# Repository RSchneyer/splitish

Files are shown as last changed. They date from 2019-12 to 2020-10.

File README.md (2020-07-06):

# splitish
My first attempt at designing a mechanical keyboard. Split-ish 4x12 ortholinear layout designed for Kailh Choc switches. Rev 1 works, but is far from perfect, so order at your own risk.
v1 assembled
version 2 now exists, but I haven't had it fabricated though. Should still work.
v2 front render
v2 back render

Firmware can be found [here](hhttps://github.com/qmk/qmk_firmware/tree/master/keyboards/splitish)
___
Made with lots of help from [Ai03's PCB design guide](https://wiki.ai03.me/books/pcb-design)

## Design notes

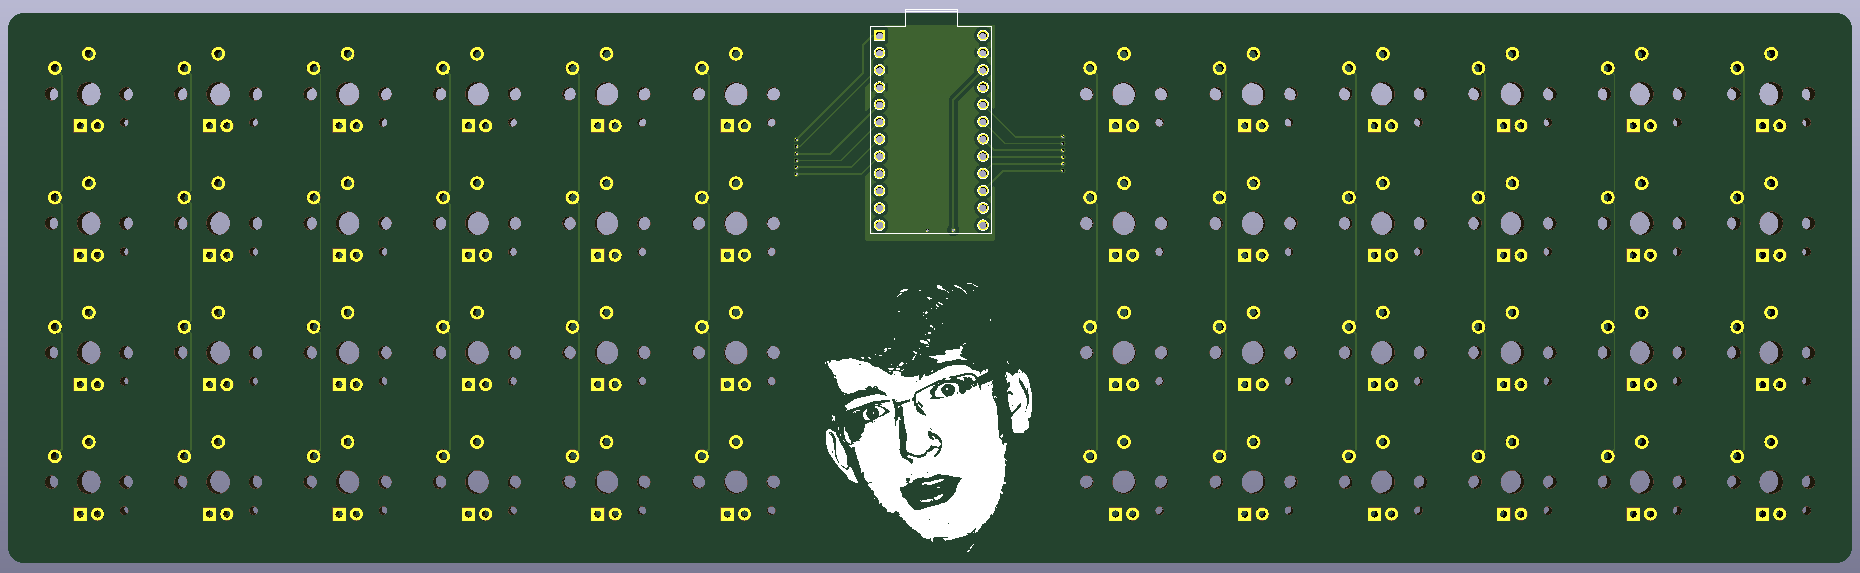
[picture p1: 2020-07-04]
media/splitish_back_v2.PNG

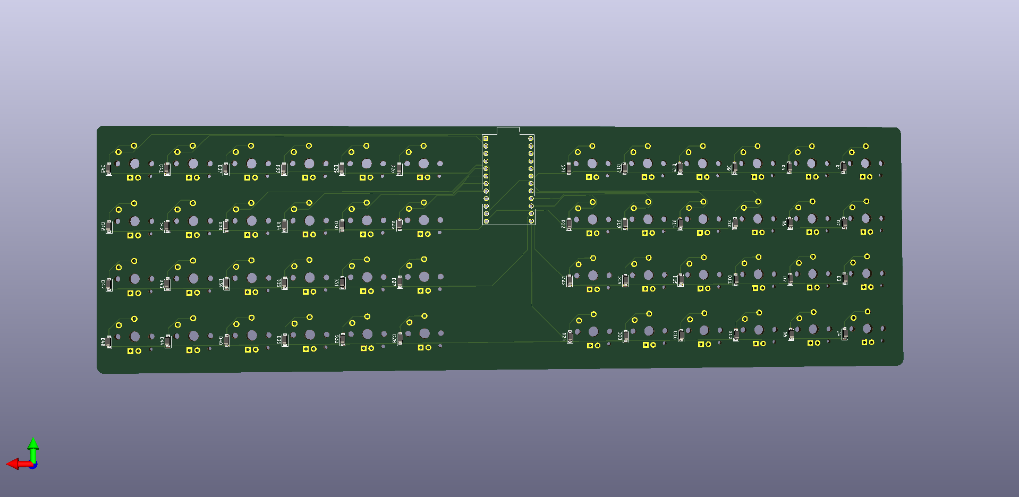
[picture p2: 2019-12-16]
media/starter-ortho-render-back.png

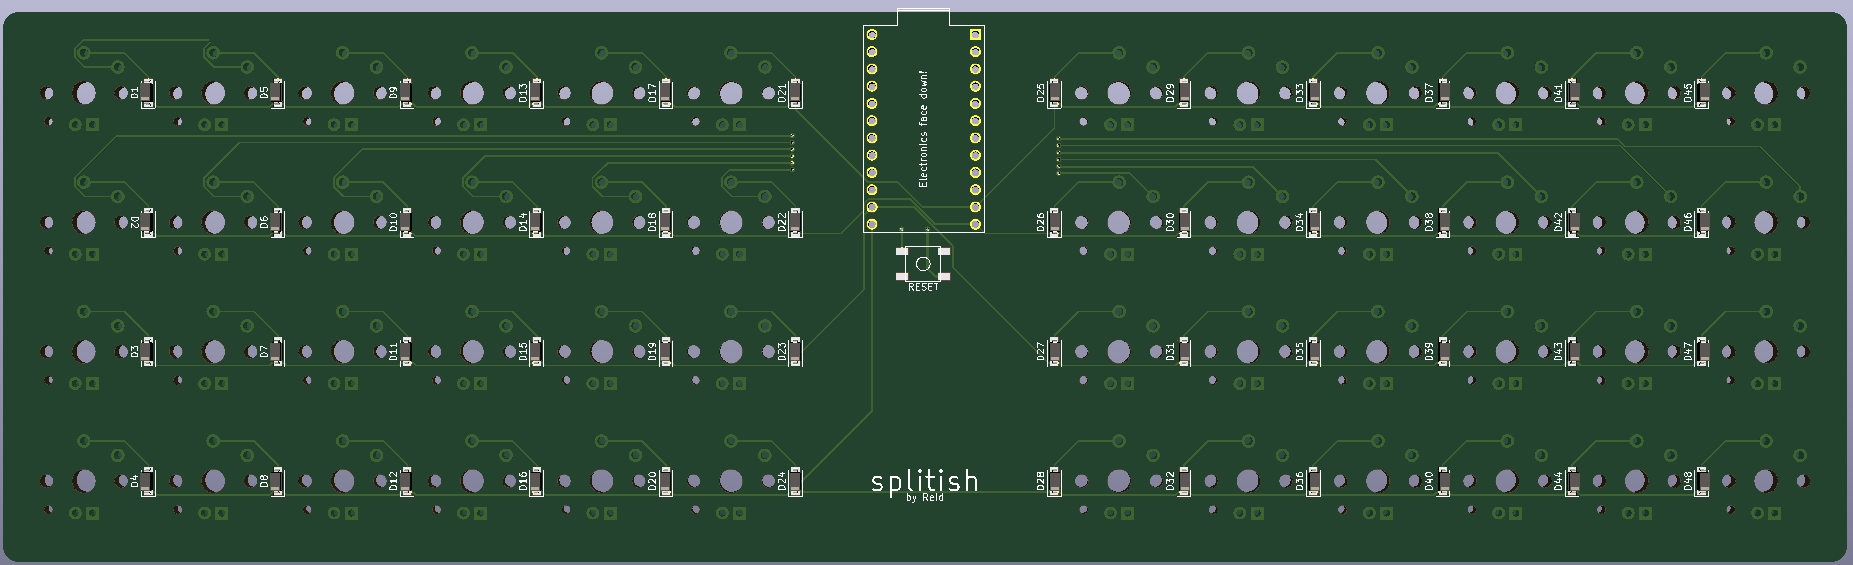
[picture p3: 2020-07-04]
media/splitish_front_v2.PNG

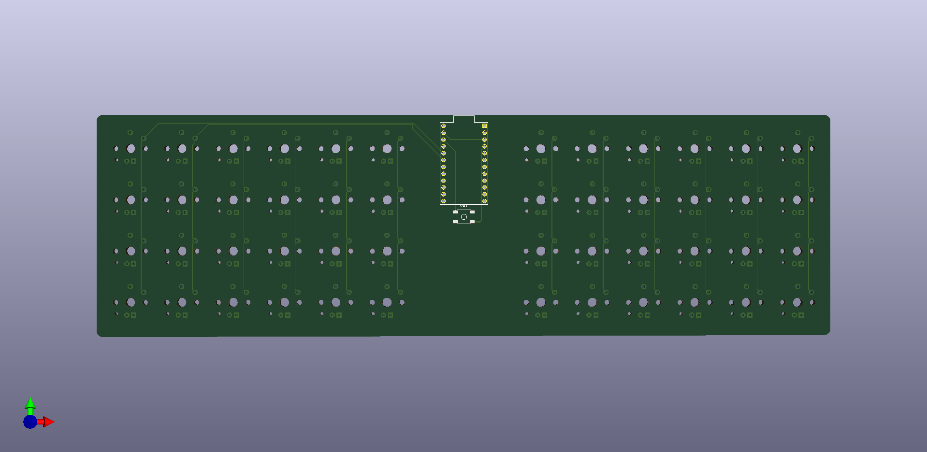
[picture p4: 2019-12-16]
media/starter-ortho-render-front.png

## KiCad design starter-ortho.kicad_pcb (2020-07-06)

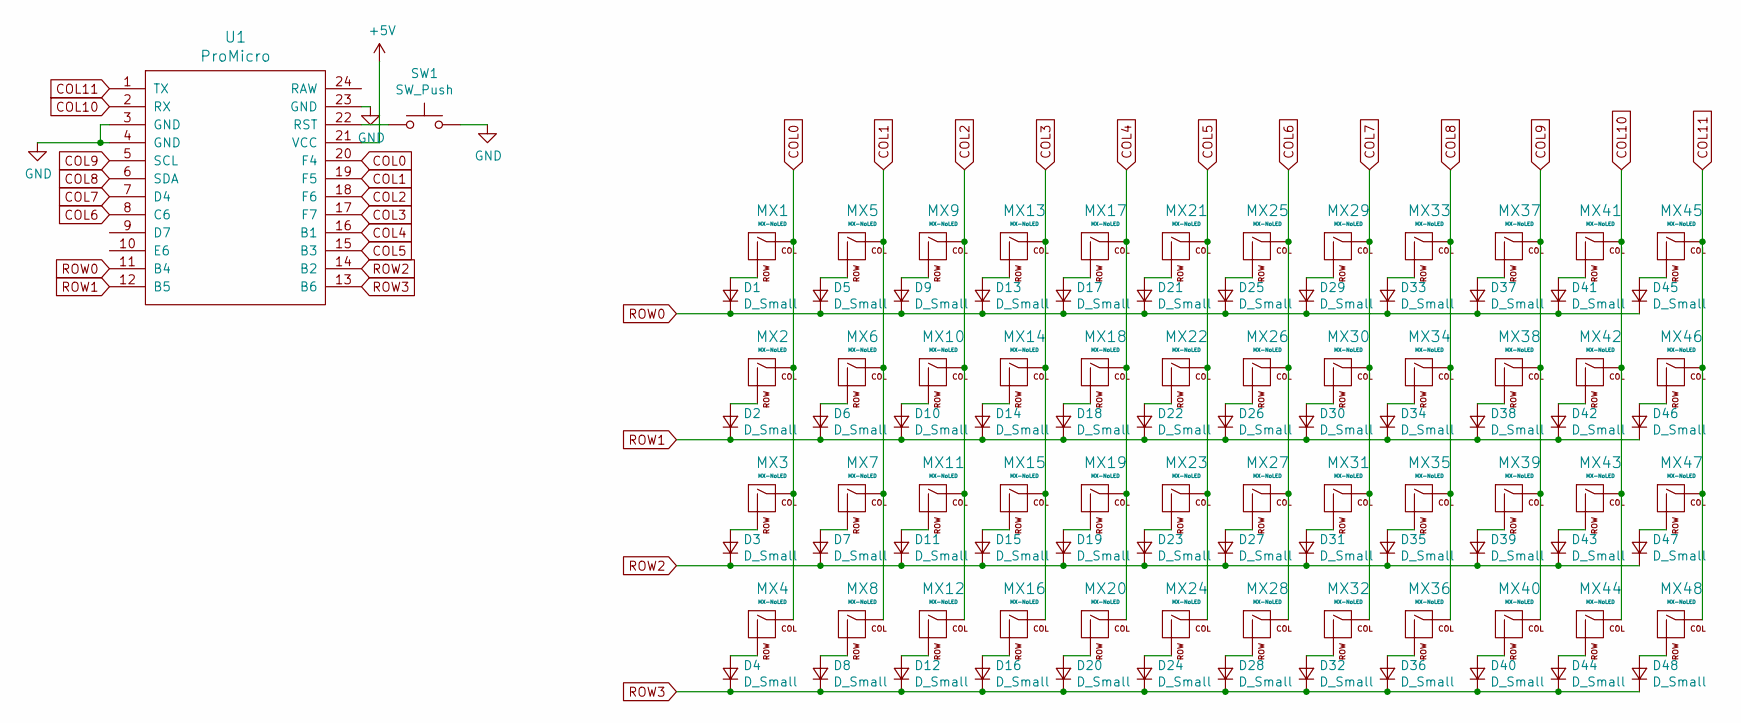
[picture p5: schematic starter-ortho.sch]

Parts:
D1, D2, D3, D4, D5, D6, D7, D8, D9, D10, D11, D12, D13, D14, D15, D16, D17, D18, D19, D20, D21, D22, D23, D24, D25, D26, D27, D28, D29, D30, D31, D32, D33, D34, D35, D36, D37, D38, D39, D40, D41, D42, D43, D44, D45, D46, D47, D48: D_Small; D_SOD-123
MX1, MX2, MX3, MX4, MX5, MX6, MX7, MX8, MX9, MX10, MX11, MX12, MX13, MX14, MX15, MX16, MX17, MX18, MX19, MX20, MX21, MX22, MX23, MX24, MX25, MX26, MX27, MX28, MX29, MX30, MX31, MX32, MX33, MX34, MX35, MX36, MX37, MX38, MX39, MX40, MX41, MX42, MX43, MX44, MX45, MX46, MX47, MX48: MX-NoLED; KailhChoc-1U
SW1: SW_Push; SKQG-1155865
U1: ProMicro

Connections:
+5V: U1.21 (VCC)
COL0: MX1.1 (COL), MX2.1 (COL), MX3.1 (COL), MX4.1 (COL), U1.20 (F4)
COL1: MX5.1 (COL), MX6.1 (COL), MX7.1 (COL), MX8.1 (COL), U1.19 (F5)
COL2: MX9.1 (COL), MX10.1 (COL), MX11.1 (COL), MX12.1 (COL), U1.18 (F6)
COL3: MX13.1 (COL), MX14.1 (COL), MX15.1 (COL), MX16.1 (COL), U1.17 (F7)
COL4: MX17.1 (COL), MX18.1 (COL), MX19.1 (COL), MX20.1 (COL), U1.16 (B1)
COL5: MX21.1 (COL), MX22.1 (COL), MX23.1 (COL), MX24.1 (COL), U1.15 (B3)
COL6: MX25.1 (COL), MX26.1 (COL), MX27.1 (COL), MX28.1 (COL), U1.8 (C6)
COL7: MX29.1 (COL), MX30.1 (COL), MX31.1 (COL), MX32.1 (COL), U1.7 (D4)
COL8: MX33.1 (COL), MX34.1 (COL), MX35.1 (COL), MX36.1 (COL), U1.6 (SDA)
COL9: MX37.1 (COL), MX38.1 (COL), MX39.1 (COL), MX40.1 (COL), U1.5 (SCL)
COL10: MX41.1 (COL), MX42.1 (COL), MX43.1 (COL), MX44.1 (COL), U1.2 (RX)
COL11: MX45.1 (COL), MX46.1 (COL), MX47.1 (COL), MX48.1 (COL), U1.1 (TX)
GND: SW1.2, U1.3 (GND), U1.4 (GND), U1.23 (GND); also elsewhere on the board
unnamed: D1.2 (A), MX1.2 (ROW)
unnamed: D2.2 (A), MX2.2 (ROW)
unnamed: D3.2 (A), MX3.2 (ROW)
unnamed: D4.2 (A), MX4.2 (ROW)
unnamed: D5.2 (A), MX5.2 (ROW)
unnamed: D6.2 (A), MX6.2 (ROW)
unnamed: D7.2 (A), MX7.2 (ROW)
unnamed: D8.2 (A), MX8.2 (ROW)
unnamed: D9.2 (A), MX9.2 (ROW)
unnamed: D10.2 (A), MX10.2 (ROW)
unnamed: D11.2 (A), MX11.2 (ROW)
unnamed: D12.2 (A), MX12.2 (ROW)
unnamed: D13.2 (A), MX13.2 (ROW)
unnamed: D14.2 (A), MX14.2 (ROW)
unnamed: D15.2 (A), MX15.2 (ROW)
unnamed: D16.2 (A), MX16.2 (ROW)
unnamed: D17.2 (A), MX17.2 (ROW)
unnamed: D18.2 (A), MX18.2 (ROW)
unnamed: D19.2 (A), MX19.2 (ROW)
unnamed: D20.2 (A), MX20.2 (ROW)
unnamed: D21.2 (A), MX21.2 (ROW)
unnamed: D22.2 (A), MX22.2 (ROW)
unnamed: D23.2 (A), MX23.2 (ROW)
unnamed: D24.2 (A), MX24.2 (ROW)
unnamed: D25.2 (A), MX25.2 (ROW)
unnamed: D26.2 (A), MX26.2 (ROW)
unnamed: D27.2 (A), MX27.2 (ROW)
unnamed: D28.2 (A), MX28.2 (ROW)
unnamed: D29.2 (A), MX29.2 (ROW)
unnamed: D30.2 (A), MX30.2 (ROW)
unnamed: D31.2 (A), MX31.2 (ROW)
unnamed: D32.2 (A), MX32.2 (ROW)
unnamed: D33.2 (A), MX33.2 (ROW)
unnamed: D34.2 (A), MX34.2 (ROW)
unnamed: D35.2 (A), MX35.2 (ROW)
unnamed: D36.2 (A), MX36.2 (ROW)
unnamed: D37.2 (A), MX37.2 (ROW)
unnamed: D38.2 (A), MX38.2 (ROW)
unnamed: D39.2 (A), MX39.2 (ROW)
unnamed: D40.2 (A), MX40.2 (ROW)
unnamed: D41.2 (A), MX41.2 (ROW)
unnamed: D42.2 (A), MX42.2 (ROW)
unnamed: D43.2 (A), MX43.2 (ROW)
unnamed: D44.2 (A), MX44.2 (ROW)
unnamed: D45.2 (A), MX45.2 (ROW)
unnamed: D46.2 (A), MX46.2 (ROW)
unnamed: D47.2 (A), MX47.2 (ROW)
unnamed: D48.2 (A), MX48.2 (ROW)
unnamed 62: SW1.1, U1.22 (RST); also elsewhere on the board
ROW0: D1.1 (K), D5.1 (K), D9.1 (K), D13.1 (K), D17.1 (K), D21.1 (K), D25.1 (K), D29.1 (K), D33.1 (K), D37.1 (K), D41.1 (K), D45.1 (K), U1.11 (B4)
ROW1: D2.1 (K), D6.1 (K), D10.1 (K), D14.1 (K), D18.1 (K), D22.1 (K), D26.1 (K), D30.1 (K), D34.1 (K), D38.1 (K), D42.1 (K), D46.1 (K), U1.12 (B5)
ROW2: D3.1 (K), D7.1 (K), D11.1 (K), D15.1 (K), D19.1 (K), D23.1 (K), D27.1 (K), D31.1 (K), D35.1 (K), D39.1 (K), D43.1 (K), D47.1 (K), U1.14 (B2)
ROW3: D4.1 (K), D8.1 (K), D12.1 (K), D16.1 (K), D20.1 (K), D24.1 (K), D28.1 (K), D32.1 (K), D36.1 (K), D40.1 (K), D44.1 (K), D48.1 (K), U1.13 (B6)

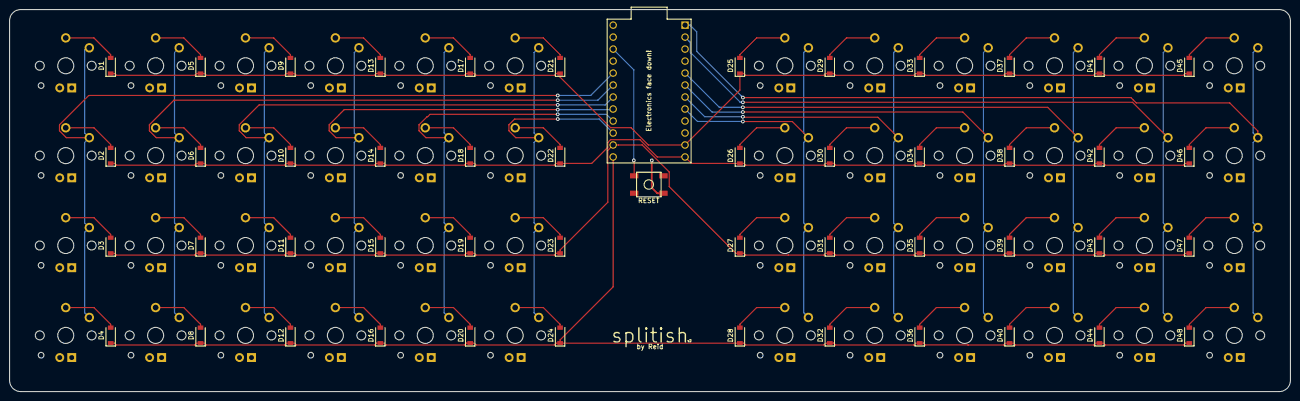
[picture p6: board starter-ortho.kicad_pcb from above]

Board: 2 copper layers, 271.5 x 81.0 mm, 98 parts (1 on the bottom side), 66 nets.

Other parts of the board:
RESET: SW_Push; SKQG-1155865

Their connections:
GND: RESET.2; also elsewhere on the board
unnamed 62: RESET.1; also elsewhere on the board

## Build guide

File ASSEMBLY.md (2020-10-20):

# Assembling the splitish

## Parts List
| Item | Quantity | Price | Where to Buy | Notes |
|---|---|---|---|---|
| splitish PCB | 1 | ~$25/5 PCBs  | JLCPCB (or your preferred PCB fab) | |
| Kailh Choc Switches | 48 | $6/10 switches | [Novelkeys](https://novelkeys.xyz/collections/switches/products/kailh-low-profile-switches)  | |
| Kailh Choc Keycaps  | 48 | ??? | ??? | NK used to carry them, idk where to get them now |
| Pro Micro | 1 | $7.99 | [SpaceCat](https://spacecat.design/collections/do-it-yourself/products/pro-micro-board) | Elite-C should also work, if you wanna spend $$$ |
| SMD Reset Switch | 1 | $0.69 | [SpaceCat](https://spacecat.design/collections/do-it-yourself/products/smd-switch-alps) | |
| 1N4148W-TP Diodes | 48 | $0.17/each | [Digi-Key](https://www.digikey.com/en/products/detail/micro-commercial-co/1N4148W-TP/717311) | |
| Rubber Feet | Many | Depends | [Amazon](https://www.amazon.com/322Pcs-Cabinet-Bumpers-Adhesive-Dampening/dp/B07BHP4NGY) | I'm sure there are plenty of other alternatives  |

## Step 1
Carefully solder all 48 SMD diodes to the bottom of the PCB. On both versions of the splitish PCB, the Cathode end of the diode (the end with the little line) should be facing the user when the keyboard is being used.

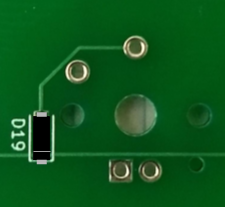
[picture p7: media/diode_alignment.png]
diode alignment


# Step 2
Now that all 48 diodes are properly soldered, you can solder in all 48 switches. The switches should have PCB mount legs that will help align the switch and keep it in place while you solder the metal pins, but a piece of tape can also be used to hold a switch in place.

# Step 3
After soldering all the switches, the next step is to solder the reset button and the Pro Micro. Solder the header pin strips to the PCB first, then the Pro Micro on top, aligned so that all the onboard components face the splitish PCB.

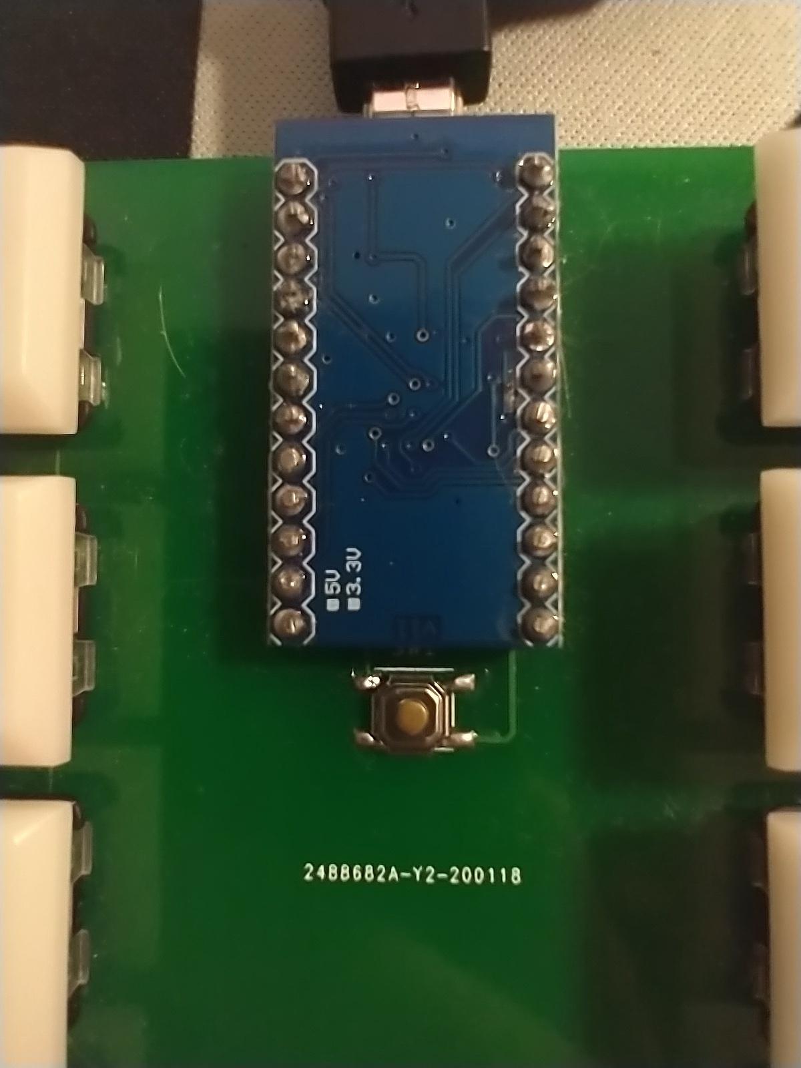
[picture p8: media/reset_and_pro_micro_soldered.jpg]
pro micro and diode


# Step 4
Attach the rubber bumpons/feet to the underside of the PCB, so that all the solder joints are not touching the work surface. Attach the keycaps, and using QMK, flash the default firmware to the splitish. Assuming you have a QMK environment properly setup on your PC, the command should be

`qmk compile -kb splitish -km default`

Assuming the keyboard now works, you're done with assembly! Wasn't that easy?

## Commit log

2019-12-16 Inital Commit
    [starter-ortho.kicad_pcb, starter-ortho.sch]
2019-12-16 schematic complete
2019-12-16 created PCB layout
    [starter-ortho.sch]
2019-12-16 Added edges and M2 holes
    [starter-ortho.kicad_pcb]
2019-12-16 Routed traces (poorly)
    [starter-ortho.kicad_pcb, starter-ortho.sch]
2019-12-16 undid edge cuts
    [starter-ortho.kicad_pcb]
2019-12-16 we're doing choc switches now baby
    [starter-ortho.kicad_pcb, starter-ortho.sch]
2019-12-16 all traces routed
    done well? we'll see...
    [starter-ortho.kicad_pcb, starter-ortho.sch]
2019-12-16 PCB done?
    [starter-ortho.kicad_pcb]
2019-12-16 removed name from silkscreen
    [starter-ortho.kicad_pcb]
2019-12-16 generated gerber files
    [starter-ortho-B_Cu.gbl, starter-ortho-B_Mask.gbs, starter-ortho-B_SilkS.gbo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]
2019-12-16 re-added silkscreen
    [starter-ortho.kicad_pcb]
2020-01-17 Added silkscreen text for promicro (and other updates)
    [starter-ortho.kicad_pcb]
2020-01-17 Fixing DRC errors
    [starter-ortho.kicad_pcb]
2020-01-17 Regenerated gerber files and zipped them
    [starter-ortho-B_Cu.gbl, starter-ortho-B_Mask.gbs, starter-ortho-B_SilkS.gbo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]
2020-04-09 updated readme with photo of assembled board
2020-07-04 created splitish v2
    [starter-ortho.kicad_pcb]
2020-07-04 created and zipped v2 gerbers
    [starter-ortho-B_Cu.gbl, starter-ortho-B_Mask.gbs, starter-ortho-B_SilkS.gbo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]
2020-07-06 deleted unused traces and remade gerbers
    [starter-ortho-B_Cu.gbl, starter-ortho-B_Mask.gbs, starter-ortho-B_SilkS.gbo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]
2020-10-20 Added assembly docs
2020-10-20 Quick update to assembly docs
